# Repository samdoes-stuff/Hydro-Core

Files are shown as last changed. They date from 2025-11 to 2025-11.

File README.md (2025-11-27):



# Hydro-Core

HydroCore was specifically made for using Ethernet and as well as Pixhawk with my mobile phone, because I was working on an underwater drone project. There, I needed, like, mobile—if I can connect the internet with my mobile phone and the Pixhawk Mavlink telemetry connection with my mobile phone, it will be so good, because mobile phones have better capability—like power capability, processing power, using camera for live feed and above all the low power workload. And from that, I was inspired to make this board, which basically converts Ethernet to USB and converts UART to USB, and those are connected with a USB hub IC, which combines to use one upstream output, which then connects to my mobile phone.

# PCB Design

So I haven't designed my software yet, but this is my PCB design. My PCB design contains:

an Ethernet port with a PHY controller,

necessary components to support this,

the UART controller chip to USB converter,

a USB converter IC,

and the full board is a self-powered board.

All of the power is given by an external power source; it doesn't come from the mobile phone.

# Mobile Charging Feature

Another fun fact is, because my mobile phone will be connected to the board all the time, it will be power draining for most of the time. There was no quite good solution for, like, charging my mobile, so what I did—I made a connection, I made an upstream charger with an upstream charger IC, where it can charge my mobile phone as well as connect to the devices.

# Challenges and Learning

And that is all for this PCB. And in this PCB, it was really a challenge for me, because it was my first time designing such a board, and I wanted it to be a very compact board. So I needed to work with so many connections, because there were so many connections. I had to learn about layers, I had to learn about ground cores, thermal relief pads, thermal relief connections, you know, there are vias, what is the impedance between the wire—I had to learn so many things. So it was quite a learning project for me, and I'm really grateful.









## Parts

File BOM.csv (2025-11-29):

ID | Name | Supplier | Quantity | MOQ | Manufacturer Part | Unit Price | Extended | Supplier Part
0 | 4.7uF | LCSC | 1 | 50 | 0402X475K100NT | $0.008 | $0.40 | C191541
1 | 100nF | ,, | 4 | 100 | 0402B104K160NT | $0.0009 | $0.09 | C41851
2 | 1uF | ,, | 1 | 100 | 0402X105M100NT | $0.0018 | $0.18 | C20616247
3 | 10uF | ,, | 1 | 50 | 0603X106K100NT | $0.0076 | $0.38 | C38898
4 | 10uF | ,, | 1 | 20 | 1206B106K160NT | $0.0318 | $0.64 | C39127
5 | 39pF | ,, | 2 | 100 | 0402CG390J500NT | $0.0011 | $0.11 | C1563
6 | 100nF | ,, | 1 | 100 | 0402B104J160NT | $0.0017 | $0.17 | C507422
7 | 2.2uF | ,, | 2 | 100 | 0402X225K6R3NT | $0.0046 | $0.46 | C193620
8 | 100nF | ,, | 14 | 100 | CC0402KRX5R6BB104 | $0.0012 | $0.12 | C129131
9 | 1uF | ,, | 1 | 100 | 0402X105K100NT | $0.0022 | $0.22 | C157353
10 | 10uF | ,, | 6 | 100 | 0402X106M6R3NT | $0.0068 | $0.68 | C163694
11 | 10uF | ,, | 1 | 20 | RVT1E100M0405 10UF 25V | $0.0147 | $0.29 | C970655
12 | 680uF | ,, | 1 | 5 | GVE1E687M1010CN | $0.1144 | $0.57 | C22383566
13 | 220uF | ,, | 1 | 1 | EEETC1V221P | $0.4264 | $0.43 | C242130
14 | 22uF | ,, | 1 | 5 | CA45-A-10V-22uF-K | $0.2016 | $1.01 | C503893
15 | 100nF | ,, | 1 | 50 | CT41G-0805-2X1-50V-0.1uF-M(N) | $0.0077 | $0.39 | C138340
16 | 22uF | ,, | 4 | 10 | 1206X226K100NT | $0.0364 | $0.36 | C1859
17 | 1nF | ,, | 1 | 30 | 1206B102K202NT | $0.0087 | $0.26 | C9196
18 | 1N5824 | ,, | 1 | 5 | 1N5824 | $0.0937 | $0.47 | C7503125
19 | PZ254R-11-05P | ,, | 1 | 20 | PZ254R-11-05P | $0.033 | $0.66 | C492413
20 | HCB2012KF-601T20 | ,, | 1 | 50 | HCB2012KF-601T20 | $0.0126 | $0.63 | C304329
21 | 2.2uH | ,, | 1 | 30 | ANR3015T2R2M | $0.0333 | $0.67 | C6364793
22 | 33uH | ,, | 1 | 1 | SMDRS1275-330N | $0.4284 | $0.43 | C163685
23 | 1uH | ,, | 1 | 10 | PRS3015-1R0NT | $0.0403 | $0.40 | C96144
24 | 1kΩ | ,, | 2 | 100 | RC-02K1001FT | $0.0006 | $0.06 | C140197
25 | 2.49kΩ | ,, | 1 | 100 | RC-02K2491FT | $0.0003 | $0.03 | C140190
26 | 10kΩ | ,, | 4 | 100 | RC-02K103JT | $0.0005 | $0.05 | C453512
27 | 1.1kΩ | ,, | 2 | 100 | RC-02K1101FT | $0.0005 | $0.05 | C140223
28 | 22Ω | ,, | 2 | 100 | RC-02K22R0FT | $0.0006 | $0.06 | C324769
29 | 2Ω | ,, | 2 | 100 | RS-03L2R00FT | $0.0016 | $0.16 | C322115
30 | HC911130A-M893-A | ,, | 1 | 1 | HC612601A-M893-A | $2.1081 | $2.11 | C3021368
31 | SL2.1A | ,, | 1 | 5 | SL2.1A | $0.2259 | $1.13 | C192893
32 | CP2102-GMR | ,, | 1 | 1 | CP2102-GMR | $2.0802 | $2.08 | C6568
33 | RTL8153B-VB-CG | ,, | 1 | 1 | RTL8153B-VB-CG | $3.1424 | $3.14 | C2802072
34 | TPD1E10B06DPYR | ,, | 6 | 20 | TPD1E10B06DPYR | $0.0347 | $0.69 | C48260
35 | IP5306 | ,, | 1 | 5 | IP5306 | $0.2663 | $1.33 | C181692
36 | SY8089AAAC | ,, | 1 | 5 | SY8089AAAC | $0.1406 | $0.70 | C78988
37 | 93LC46/SN_C615396 | ,, | 1 | 1 | 93LC46/SN | $1.49 | $1.49 | C615396
38 | LM2596SX-5.0/NOPB | ,, | 1 | 1 | LM2596SX-5.0/NOPB | $0.8835 | $0.88 | C10002
39 | AMS1117-3.3 | ,, | 1 | 5 | AMS1117-3.3 | $0.1641 | $0.82 | C6186
40 | XL-3216UWC | ,, | 4 | 50 | XL-3216UWC | $0.0096 | $0.48 | C965828
41 | Test-Pad | ,, | 2
42 | USB-231-BRW | ,, | 1 |  | USB-231-BRW |  |  | C720526
43 | 25MHz | ,, | 1 |  | XXHCCLNANF-25.000000 |  |  | C603160
44 | 12MHz | ,, | 1 |  | S47SMD12.000M20PF20R30B3 |  |  | C5346045
45 | PCB |  | 1 | 5 | JLCPCB | $34.49 | $0(Free Coupon)
46 | Shipping |  |  |  | JLCPCB + LCSC | $9.28 + $15.55 | $24.83
 | Total |  |  |  |  | $51.55

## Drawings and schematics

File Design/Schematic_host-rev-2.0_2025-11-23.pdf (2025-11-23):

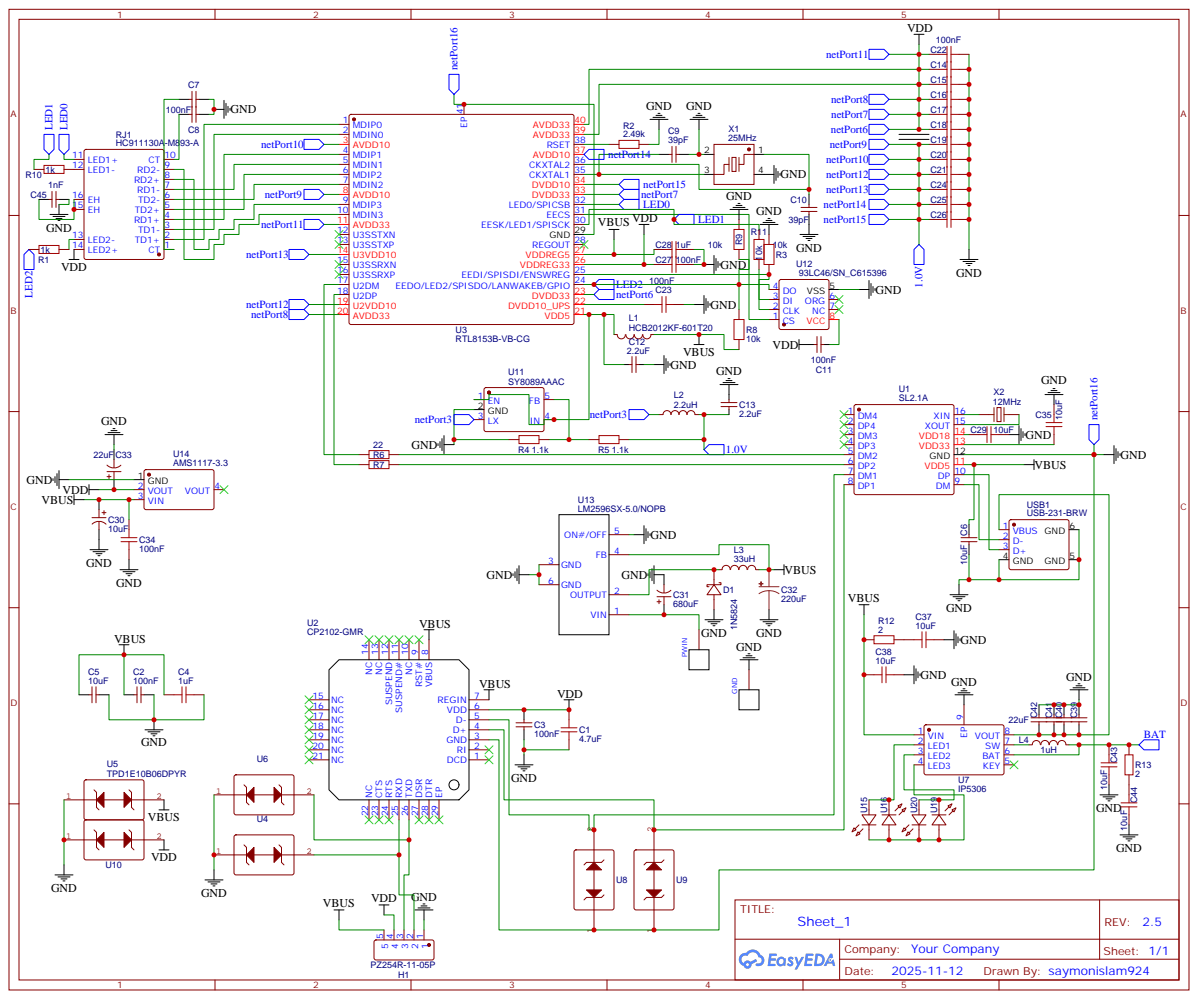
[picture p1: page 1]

9 NC 10 SUSPEND# 11 SUSPEND 12 NC 13 NC 14

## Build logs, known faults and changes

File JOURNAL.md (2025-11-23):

# Initial Concept Research (1.5 hours)
I began exploring the initial idea by studying various YouTubers and technical websites to understand different design approaches. I noticed that using separate controllers required excessive wiring and physical space. My first plan was to combine open-source Ethernet-to-USB and UART-to-USB schematics and merge them using a USB hub IC.

(Ethernet to Usb0 https://www.olimex.com/Products/USB-Modules/Ethernet/USB-GIGABIT/open-source-hardware
(Ethernet to Usb) https://github.com/OLIMEX/USB-GIGABIT/blob/master/HARDWARE/USB-GIGABIT-Rev.E/USB-GIGABIT_Rev_E.pdf
(Uart to Usb-C) https://github.com/SolderedElectronics/USB-UART-CH340C-converter-board-hardware-design

# Studying Open-Source Schematics (2 hours)

I followed open-source hardware designs, but discovered that many components were unavailable, back-stocked, or incompatible. For the Ethernet port, the magnetic-shielded connector required four differential TX/RX pairs, and I found mismatches between open-source examples and my needs. Still, the reference schematics helped a lot.


# First Schematic Attempt & Failure Realization (1.5 hours)

After around five hours of work integrating open-source parts into my schematic, I realized the design would fail. The referenced example used USB-C-to-UART only, creating back-feed issues. The PHY controller I picked was too powerful and poorly matched because everything had to operate over USB 2.0 to match my mobile phone’s OTG limitations.


# Learning Datasheets for the First Time (2 hours)

I began reading datasheets seriously for the first time in my life. I learned that datasheets include example circuits that were more helpful than any online answer or AI suggestion. ChatGPT was not reliable for exact electrical values. Going through LCSC, I finally discovered the correct controller IC that matched my USB 2.0 requirements.




# Day 2

## Restarting the Entire Schematic (5.5 hour)

I restarted my schematic from scratch. The earlier open-source designs still helped because some connections matched. Missing passive component values were found from Google searches, not ChatGPT. The UART-to-USB section was easy because the chip had a simple example diagram. The Ethernet controller was extremely difficult. It had so many complex connections that I nearly had to pull an all-nighter to finish it. I had to stay focused because if I left it halfway, I would forget the connection logic. I had to select a hub IC capable of upstreaming data reliably. FE1.1 was an option but had too many ports. I ultimately chose SL1.1 because its specs matched my project’s data flow requirements. I designed the AC input section that steps down to 5V. The example power circuits in the datasheet were extremely useful. Component sourcing was difficult because LCSC filtering takes practice. I added the upstream charging IC, letting the mobile phone charge while connected. LED indicators were integrated to show phone charging/battery status. I also built the 3V and 1V converters.


## Beginning PCB Layout (4.5)
After completing the schematic, I started PCB layout work. This was the most time-consuming stage. I tested several board outlines and dimensions to fit all components properly. Autoroute failed every time. Proper component placement became critical. I had to switch to full manual routing. I learned about impedance, trace gaps, crosstalk, thermal vias, and multilayer routing through Altium Academy and PCB guru videos. I switched between 4-layer and 6-layer designs until I understood how to use bias and planes properly. After several routing revisions and placement adjustments, I finished the board. I ran DRC checks, ensured power traces were thicker, fixed clearances, and finally completed the PCB.

Initial Layout 


Designing Back & Forth 


Final Layout 


Completed One 


Final PCB - Pretty Clean; Proud of Myself




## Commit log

2025-11-23 Gerber File
2025-11-23 PCB File
2025-11-23 Schematic Source File
2025-11-23 Schematic PDF
2025-11-23 Add detailed project journal entries
    Documented the initial concept research, schematic attempts, and PCB layout process, detailing challenges and learning experiences throughout the project.
2025-11-23 Create Uart Controller
2025-11-23 Update Uart Controller
2025-11-27 Removed Via in Pad
    [PCB_PCB_host-rev-2.0_2025-11-25 (1).pcbdoc]
